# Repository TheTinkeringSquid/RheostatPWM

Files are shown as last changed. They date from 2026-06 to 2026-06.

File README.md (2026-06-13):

# Dodge B2500 Instrument Cluster LED PWM Dimmer

Small RP2040-based PWM dimmer board for a 1996 Dodge B2500 instrument cluster
LED conversion. It reads the factory headlight rheostat as an analog input and
drives the cluster illumination feed with a protected high-side 12 V PWM output.

> **Cluster illumination only.** This board is not for exterior lighting, brake
> lights, turn signals, airbags, engine controls, or any safety-critical
> circuit.

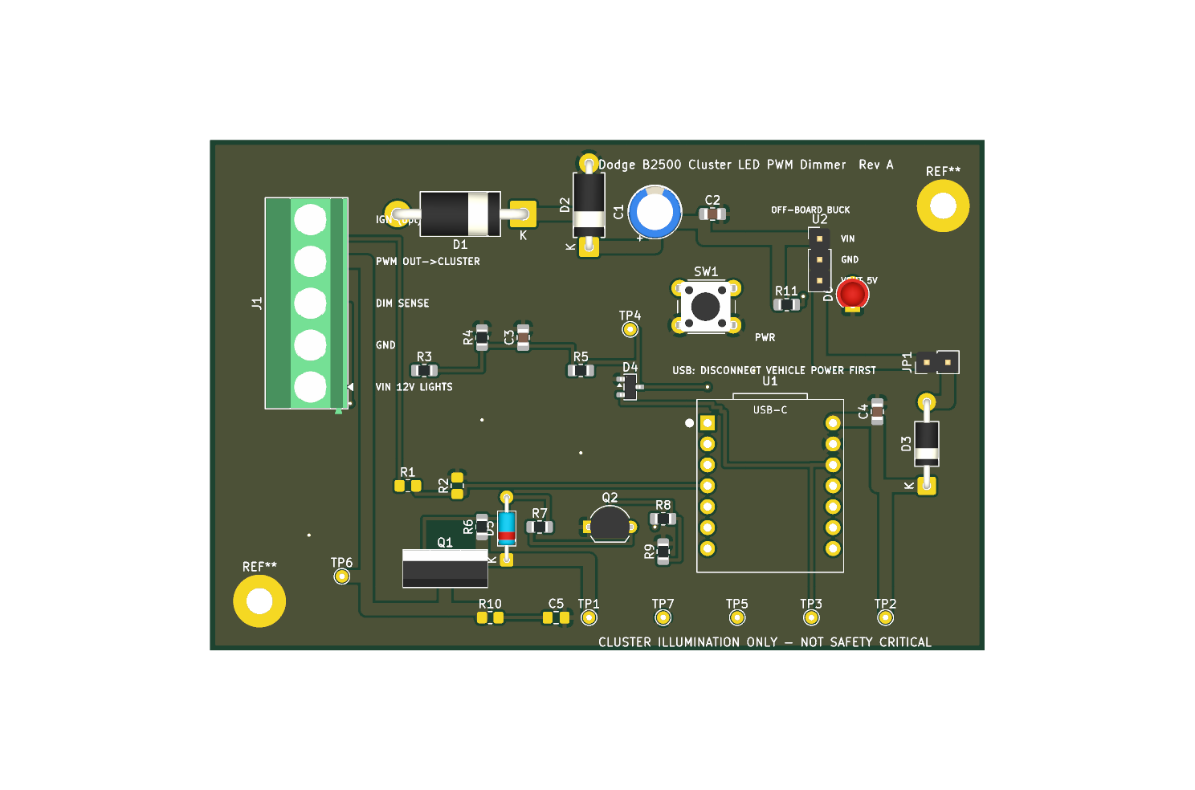
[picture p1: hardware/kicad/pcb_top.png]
PCB top view


---

## How it works

```
factory full 12 V illumination/headlamp-switched feed  -> J1 VIN_RAW
factory dimmer/rheostat analog output                  -> J1 DIM_IN  (sense only)
board high-side 12 V PWM output                        -> J1 PWM_OUT -> cluster LED +
cluster/chassis ground                                 -> J1 GND
```

The factory rheostat no longer powers the cluster lamps. It is read as a
low-current analog control signal through a high-impedance divider into the
XIAO RP2040 ADC. Firmware maps that voltage through a gamma curve to a high-side
PWM output (P-channel MOSFET Q1 driven by N-MOSFET Q2), so the lamp grounds stay
factory.

### Connector (J1)

| Pin | Net | Description |
|----:|---|---|
| 1 | `VIN_RAW`  | Fused full 12 V illumination/headlight-switched feed |
| 2 | `GND` | Chassis/cluster ground |
| 3 | `DIM_IN` | Factory rheostat output, sense only |
| 4 | `PWM_OUT`  | PWM +12 V output to cluster LED illumination feed |
| 5 | `IGN_SENSE`| Optional lights-on signal (future firmware; DNP parts) |

### Install concept

1. Identify the factory cluster illumination/dimmer feed with a multimeter and
   wiring diagram.
2. Cut or depin the cluster illumination feed so the rheostat no longer powers
   the LED bulbs directly.
3. Connect the **vehicle/rheostat side** of that wire to `DIM_IN`.
4. Connect the **cluster/lamp side** of that wire to `PWM_OUT`.
5. Power the board from a fused full-bright illumination feed that is hot when
   park/headlights are on — **not** from the dimmed rheostat output.
6. Ground the board to the cluster/chassis ground.

> Do **not** power the microcontroller from `DIM_IN`; it may brown out when the
> rheostat is turned down.
>
> If the factory dimmer turns out to be low-side, already-PWM, or multiplexed
> rather than a simple variable positive voltage, **stop** and revise the input
> circuit instead of forcing this design.

---

## Repository layout

```
.
├── README.md
├── firmware/                     PlatformIO project (Seeed XIAO RP2040)
│   ├── platformio.ini
│   └── src/main.cpp
└── hardware/
    ├── kicad/
    │   ├── b2500_cluster_pwm_dimmer.kicad_pro / .kicad_sch / .kicad_pcb
    │   ├── b2500_cluster_pwm_dimmer_schematic.pdf
    │   ├── pcb_top.png
    │   └── symbols_and_footprints/b2500.pretty/   (XIAO + Pololu module footprints)
    ├── scripts/                  generators (re-create the design deterministically)
    │   ├── netlist.py            single source of truth for the netlist
    │   ├── gen_sch.py            -> kicad_sch
    │   ├── gen_pcb.py            -> kicad_pcb
    │   ├── gen_bom.py            -> BOM CSV
    │   └── export_fab.py         -> gerbers + drill + BOM (run after routing)
    ├── gerbers/                  fabrication output (generated after routing)
    ├── fabrication_notes.md
    └── b2500_cluster_pwm_dimmer_bom.csv
```

The KiCad schematic, board, and BOM are generated by the scripts in
`hardware/scripts/`. They share `netlist.py` so the schematic and board can
never drift apart. Regenerate with:

```powershell
python hardware/scripts/gen_sch.py                       # schematic
& "C:/Program Files/KiCad/10.0/bin/python.exe" hardware/scripts/gen_pcb.py   # board (needs KiCad's Python)
python hardware/scripts/gen_bom.py                       # BOM CSV
```

---

## Firmware

Built with PlatformIO for the Seeed Studio XIAO RP2040 (Arduino / Earle
Philhower RP2040 core).

```bash
cd firmware
pio run            # build
pio run -t upload  # flash (board in UF2 bootloader, or via USB)
pio device monitor # 115200 baud serial debug
```

Key calibration constants live at the top of `firmware/src/main.cpp`
(`ADC_OFF_THRESHOLD`, `ADC_MIN_INPUT`, `ADC_MAX_INPUT`, `DUTY_MIN`, `GAMMA`,
`PWM_FREQ_HZ`, plus `REVERSE_DIMMER_DIRECTION`). Tune them on the bench against
the real dimmer using the serial output. PWM defaults to 976 Hz (in the
500 Hz–2 kHz target band).

---

## PCB

The board is **fully routed and DRC-clean** (0 violations, 0 unconnected) —
2 layers, 94 × 62 mm, ground pour on both. `hardware/scripts/gen_pcb.py`
places every part, pours ground, and routes all nets with a built-in
collision-aware router (Manhattan + maze fallback): high-current nets
(`VIN_RAW`, `PWM_OUT`, `VIN_PROT`) at 1.5 mm, signals at 0.4 mm. The gerbers and
drill files in `hardware/gerbers/` are ready to send to a fabricator.

You don't need to touch KiCad to get the board made. If you *want* to inspect or
tweak it:

1. Open `hardware/kicad/b2500_cluster_pwm_dimmer.kicad_pro` in KiCad 10.
2. Make changes, run DRC, then regenerate fabrication output:

   ```powershell
   python hardware/scripts/export_fab.py
   ```

   This runs DRC, writes gerbers + Excellon drill to `hardware/gerbers/`, and
   regenerates the BOM. (Re-running `gen_pcb.py` regenerates the whole board
   from scratch and will discard manual KiCad edits.)

### Ordering the board

Zip the contents of `hardware/gerbers/` and upload to any PCB fab (JLCPCB,
PCBWay, OSH Park, Aisler, etc.): 2-layer, 1.6 mm, 1 oz copper (2 oz is a nice
upgrade for the power path), HASL or ENIG. See
[hardware/fabrication_notes.md](hardware/fabrication_notes.md) for the full
spec, assembly notes, and the bench/in-vehicle test procedures.

---

## Deviations from the original brief

- **Board size** is ~94 × 62 mm, not the 50 × 35 mm target. The through-hole
  part set (5-pos 5.08 mm terminal block, TO-220, two modules, radial cap, seven
  test points, button) does not fit smaller while staying hand-solderable. A
  compact SMD-MOSFET / smaller-connector variant is a sensible future revision.
- **Q1 gate pull-up R6 is 10 k (brief said 47 k)** and a **DNP R10/C5 RC snubber
  footprint** sits across `PWM_OUT` — both for a cleaner, better-defined
  high-side switching edge with less ringing/EMI. Fit the snubber only if the
  bench scope shows ringing.
- **The buck regulator (U2) mounts off-board**, wired to a labeled 3-pin
  header (`VIN`/`GND`/`VOUT`). A footprint audit against the Pololu module
  showed its on-board land is easy to get wrong (6 pins incl. an offset PG, two
  GNDs); a wired connection is order-proof and far safer to assemble by hand.
- **Two M3 mounting holes** (per the BOM, M1–M2), placed diagonally — the
  terminal block fills the left edge, so a top-left hole was not possible.
- The board is routed by a **purpose-built script router**, not by hand in
  KiCad. It is DRC-clean and electrically complete, but the trace paths are
  Manhattan/maze-style rather than artistically dressed; feel free to prettify
  in the GUI if you re-spin.
- The XIAO USB-C port is not on a board edge; for in-place reflashing, prefer
  the UF2 bootloader or relocate U1 to an edge in a future revision.

## Safety

- Always fuse `VIN_RAW` (inline blade fuse in the harness — F1 is not on the
  board). Size it to the measured LED cluster current.
- Do not route the cluster output back through the factory rheostat.
- Do not connect USB while the board is vehicle-powered unless JP1 is open / the
  D3 isolation diode is fitted, to avoid 5 V backfeed.
- This is not OEM-grade load-dump protection. The TVS + wide-input regulator
  reduce risk but do not eliminate it.
- Carry a bypass jumper during early testing so the cluster lamps can be
  restored if the board fails.

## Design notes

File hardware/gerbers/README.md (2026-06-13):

# Gerbers

Fabrication output for the B2500 cluster PWM dimmer — RS-274X gerbers plus
Excellon drill files (`-PTH.drl`, `-NPTH.drl`). The board is fully routed and
DRC-clean, so these are **ready to manufacture**.

To order: zip the contents of this directory and upload to any PCB fab
(JLCPCB, PCBWay, OSH Park, Aisler, …). Settings: 2-layer, 1.6 mm, 1 oz copper
(2 oz optional for the power path), HASL or ENIG.

These files are generated, not hand-edited. Regenerate after any board change
with:

```powershell
python ../scripts/export_fab.py
```

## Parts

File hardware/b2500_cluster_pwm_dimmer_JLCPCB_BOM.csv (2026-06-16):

Comment | Designator | Footprint | LCSC Part#
100nF 50V | C2,C3 | 0805
10uF | C4 | 0805
100k 1% | R3,R9 | 0805
22k 1% | R4 | 0805
1k | R5 | 0805
10k | R6 | 0805
100R | R7,R8 | 0805
3.3k | R11 | 0805
BAT54S | D4 | SOT-23

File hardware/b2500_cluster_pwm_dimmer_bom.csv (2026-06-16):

Refs | Qty | Value | Footprint | Fit | Notes
C1 | 1 | 47uF 50V | Capacitor_THT:CP_Radial_D6.3mm_P2.50mm | FIT
C2 | 1 | 100nF 50V | Capacitor_SMD:C_0805_2012Metric_Pad1.18x1.45mm_HandSolder | FIT
C3 | 1 | 100nF | Capacitor_SMD:C_0805_2012Metric_Pad1.18x1.45mm_HandSolder | FIT
C4 | 1 | 10uF | Capacitor_SMD:C_0805_2012Metric_Pad1.18x1.45mm_HandSolder | FIT
C5 | 1 | 10nF 100V (DNP) | Capacitor_SMD:C_0805_2012Metric_Pad1.18x1.45mm_HandSolder | DNP | DNP RC snubber across PWM_OUT (fit only if edge ringing)
D1 | 1 | 1N5822 | Diode_THT:D_DO-201AD_P15.24mm_Horizontal | FIT | reverse-polarity series Schottky, >=3A >=40V
D2 | 1 | P6KE24CA | Diode_THT:D_DO-15_P10.16mm_Horizontal | FIT | TVS across protected VIN-GND
D3 | 1 | 1N5819 | Diode_THT:D_DO-41_SOD81_P10.16mm_Horizontal | FIT | optional 5V isolation diode (USB backfeed)
D4 | 1 | BAT54S | Package_TO_SOT_SMD:SOT-23 | FIT | ADC clamp to 3V3/GND
D5 | 1 | 1N5242B 12V | Diode_THT:D_DO-35_SOD27_P7.62mm_Horizontal | FIT | 12V zener, Q1 gate-source protection
D6 | 1 | Green LED (PWR) | LED_THT:LED_D3.0mm | FIT | green power-on LED (lit whenever 12V is present); 3mm through-hole
F1 | 1 | 2A mini blade, INLINE IN HARNESS |  | OFF-BOARD | OFF-BOARD: inline blade fuse in the vehicle harness; size to LED current
J1 | 1 | Phoenix MKDS-1,5-5-5.08 | TerminalBlock_Phoenix:TerminalBlock_Phoenix_MKDS-1,5-5-5.08_1x05_P5.08mm_Horizontal | FIT | 5-pos 5.08mm pluggable terminal (or locking automotive conn)
JP1 | 1 | 5V_LINK | Connector_PinHeader_2.54mm:PinHeader_1x02_P2.54mm_Vertical | FIT | open to isolate vehicle 5V during USB programming
Q1 | 1 | FQP27P06 | Package_TO_SOT_THT:TO-220-3_Vertical | FIT | >=40V Vds, >=2A, low Rds(on); TO-220
Q2 | 1 | 2N7000 | Package_TO_SOT_THT:TO-92_Inline_Wide | FIT | small logic-level N-MOSFET / 2N7000
R1 | 1 | 100k (DNP) | Resistor_SMD:R_0805_2012Metric_Pad1.20x1.40mm_HandSolder | DNP | DNP IGN-sense divider (future firmware)
R10 | 1 | 100R (DNP) | Resistor_SMD:R_0805_2012Metric_Pad1.20x1.40mm_HandSolder | DNP | DNP RC snubber across PWM_OUT (fit only if edge ringing)
R11 | 1 | 3.3k | Resistor_SMD:R_0805_2012Metric_Pad1.20x1.40mm_HandSolder | FIT | series resistor for D6 power LED (~3 mA at 12 V)
R2 | 1 | 22k (DNP) | Resistor_SMD:R_0805_2012Metric_Pad1.20x1.40mm_HandSolder | DNP | DNP IGN-sense divider (future firmware)
R3 | 1 | 100k 1% | Resistor_SMD:R_0805_2012Metric_Pad1.20x1.40mm_HandSolder | FIT
R4 | 1 | 22k 1% | Resistor_SMD:R_0805_2012Metric_Pad1.20x1.40mm_HandSolder | FIT
R5 | 1 | 1k | Resistor_SMD:R_0805_2012Metric_Pad1.20x1.40mm_HandSolder | FIT
R6 | 1 | 10k | Resistor_SMD:R_0805_2012Metric_Pad1.20x1.40mm_HandSolder | FIT
R7,R8 | 2 | 100R | Resistor_SMD:R_0805_2012Metric_Pad1.20x1.40mm_HandSolder | FIT
R9 | 1 | 100k | Resistor_SMD:R_0805_2012Metric_Pad1.20x1.40mm_HandSolder | FIT
SW1 | 1 | CAL | Button_Switch_THT:SW_PUSH_6mm | FIT
TP1 | 1 | TP_VIN | TestPoint:TestPoint_THTPad_D1.5mm_Drill0.7mm | FIT
TP2 | 1 | TP_5V | TestPoint:TestPoint_THTPad_D1.5mm_Drill0.7mm | FIT
TP3 | 1 | TP_3V3 | TestPoint:TestPoint_THTPad_D1.5mm_Drill0.7mm | FIT
TP4 | 1 | TP_DIM_ADC | TestPoint:TestPoint_THTPad_D1.5mm_Drill0.7mm | FIT
TP5 | 1 | TP_PWM_GATE | TestPoint:TestPoint_THTPad_D1.5mm_Drill0.7mm | FIT
TP6 | 1 | TP_PWM_OUT | TestPoint:TestPoint_THTPad_D1.5mm_Drill0.7mm | FIT
TP7 | 1 | TP_GND | TestPoint:TestPoint_THTPad_D1.5mm_Drill0.7mm | FIT
U1 | 1 | XIAO RP2040 | b2500:XIAO_RP2040_THT | FIT | Seeed XIAO RP2040 module on 2x7 socket headers
U2 | 1 | Pololu D36V28F5 (off-board, wired) | Connector_PinHeader_2.54mm:PinHeader_1x03_P2.54mm_Vertical | FIT | Pololu D36V28F5 buck module, mounted OFF-BOARD; wire its VIN/GND/VOUT to the 3-pin header (match label to label)

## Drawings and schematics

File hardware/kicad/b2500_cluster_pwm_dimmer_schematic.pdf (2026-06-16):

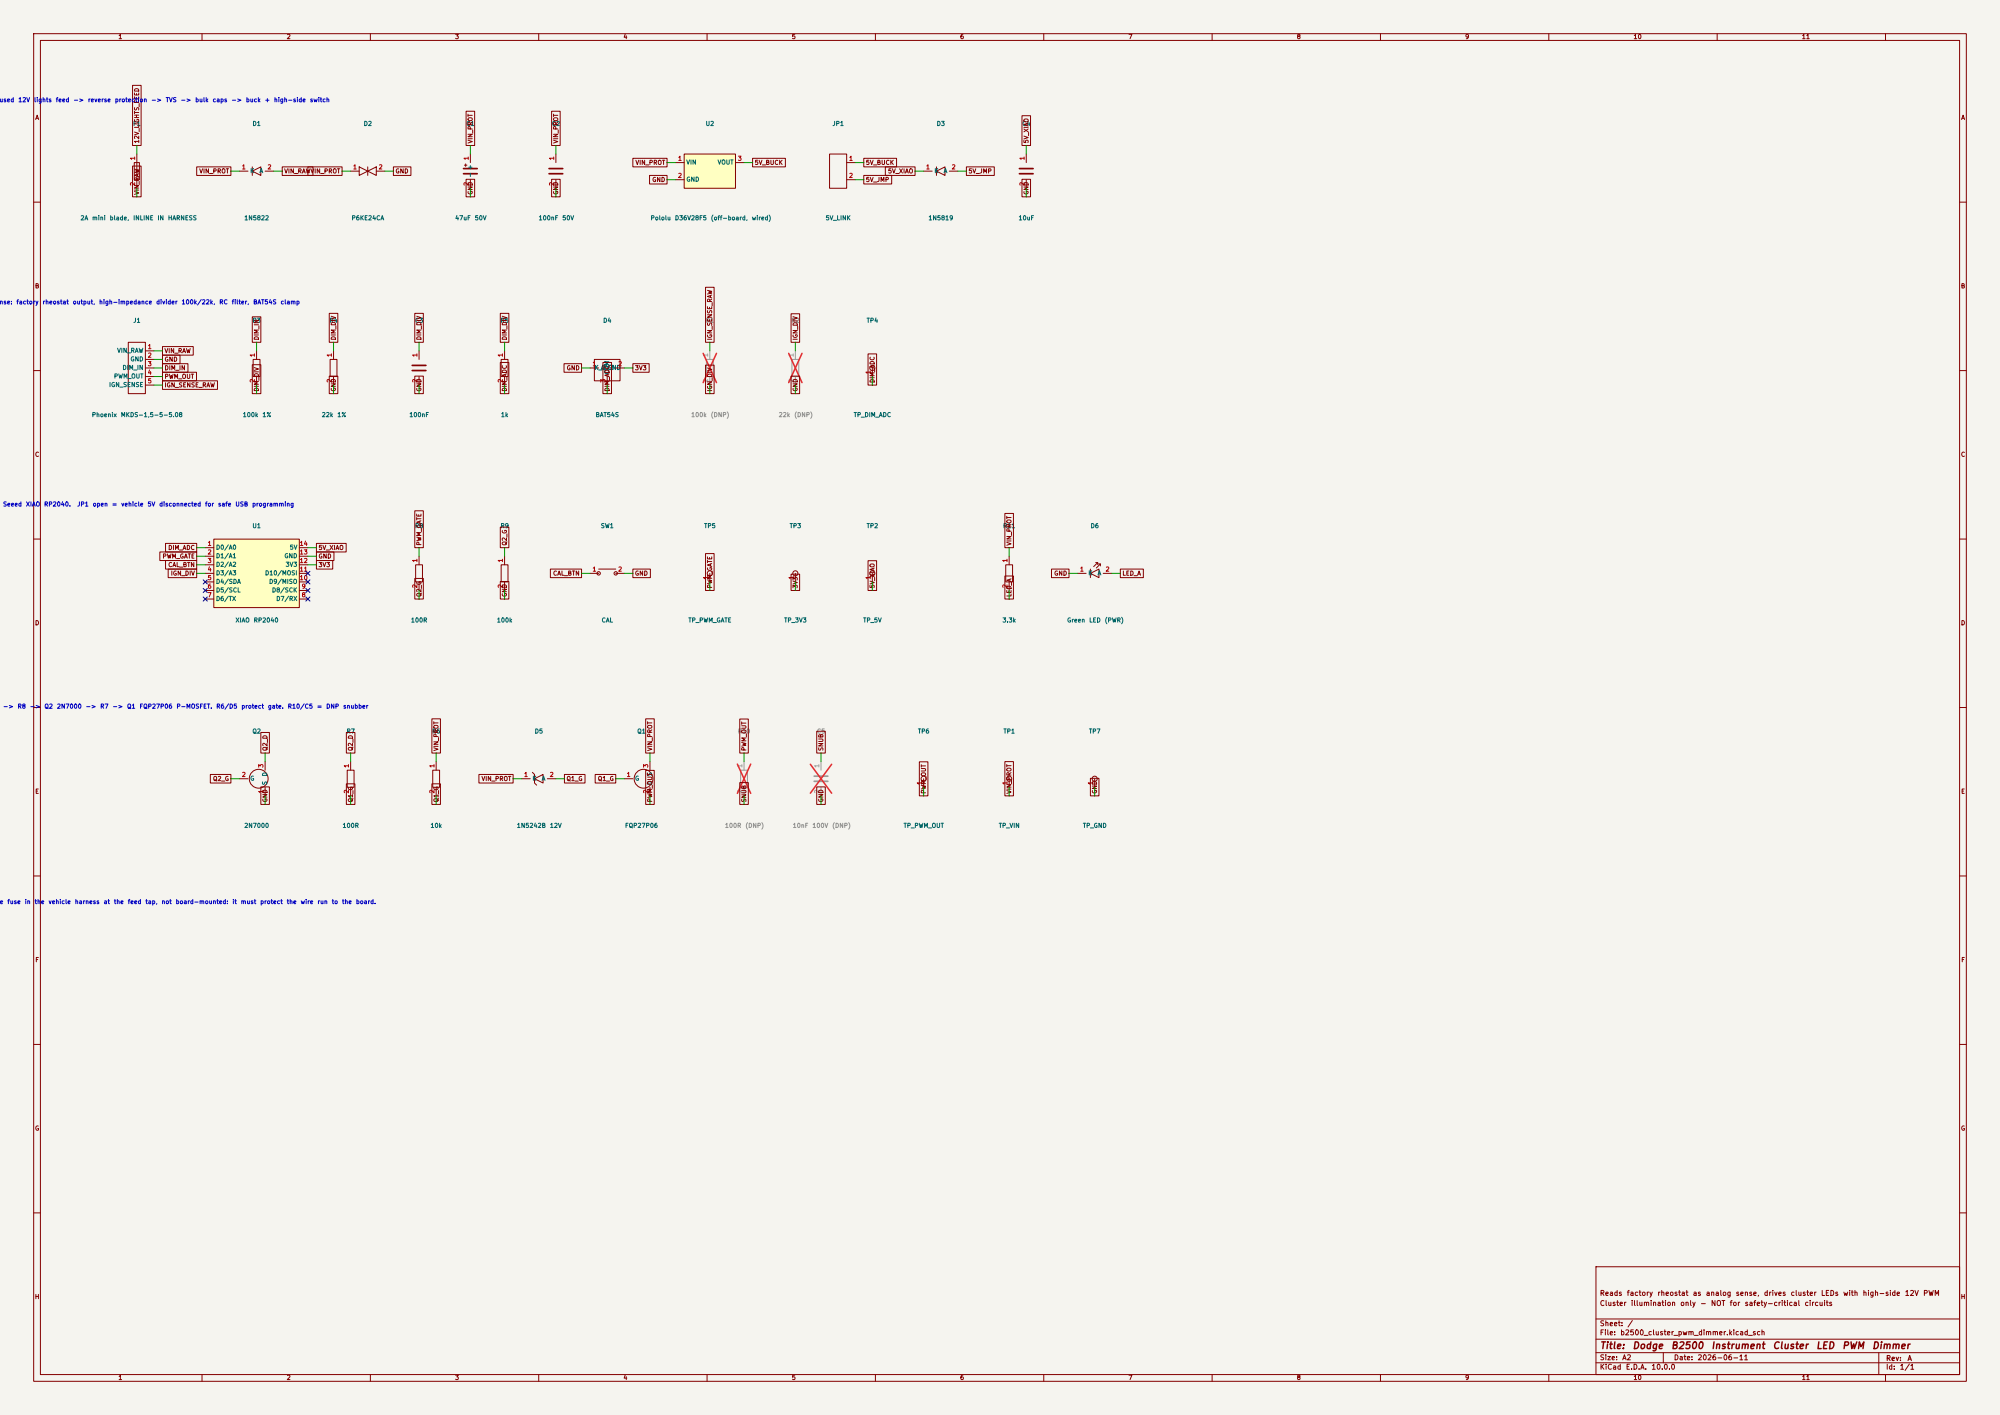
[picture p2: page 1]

Power input: fused 12V lights feed -> reverse protection -> TVS -> bulk caps -> buck + high-side switch

2A mini blade, INLINE IN HARNESS

DIM sense: factory rheostat output, high-impedance divider 100k/22k, RC filter, BAT54S clamp

MCU: Seeed XIAO RP2040. JP1 open = vehicle 5V disconnected for safe USB programming

3V3 High-side PWM: D1(MCU) -> R8 -> Q2 2N7000 -> R7 -> Q1 FQP27P06 P-MOSFET. R6/D5 protect gate. R10/C5 = DNP snubber F1 is an INLINE mini-blade fuse in the vehicle harness at the feed tap, not board-mounted: it must protect the wire run to the board.

Cluster illumination only - NOT for safety-critical circuits Reads factory rheostat as analog sense, drives cluster LEDs with high-side 12V PWM

Sheet: /
File: b2500_cluster_pwm_dimmer.kicad_sch
Title: Dodge B2500 Instrument Cluster LED PWM Dimmer

Size: A2 | Rev: A

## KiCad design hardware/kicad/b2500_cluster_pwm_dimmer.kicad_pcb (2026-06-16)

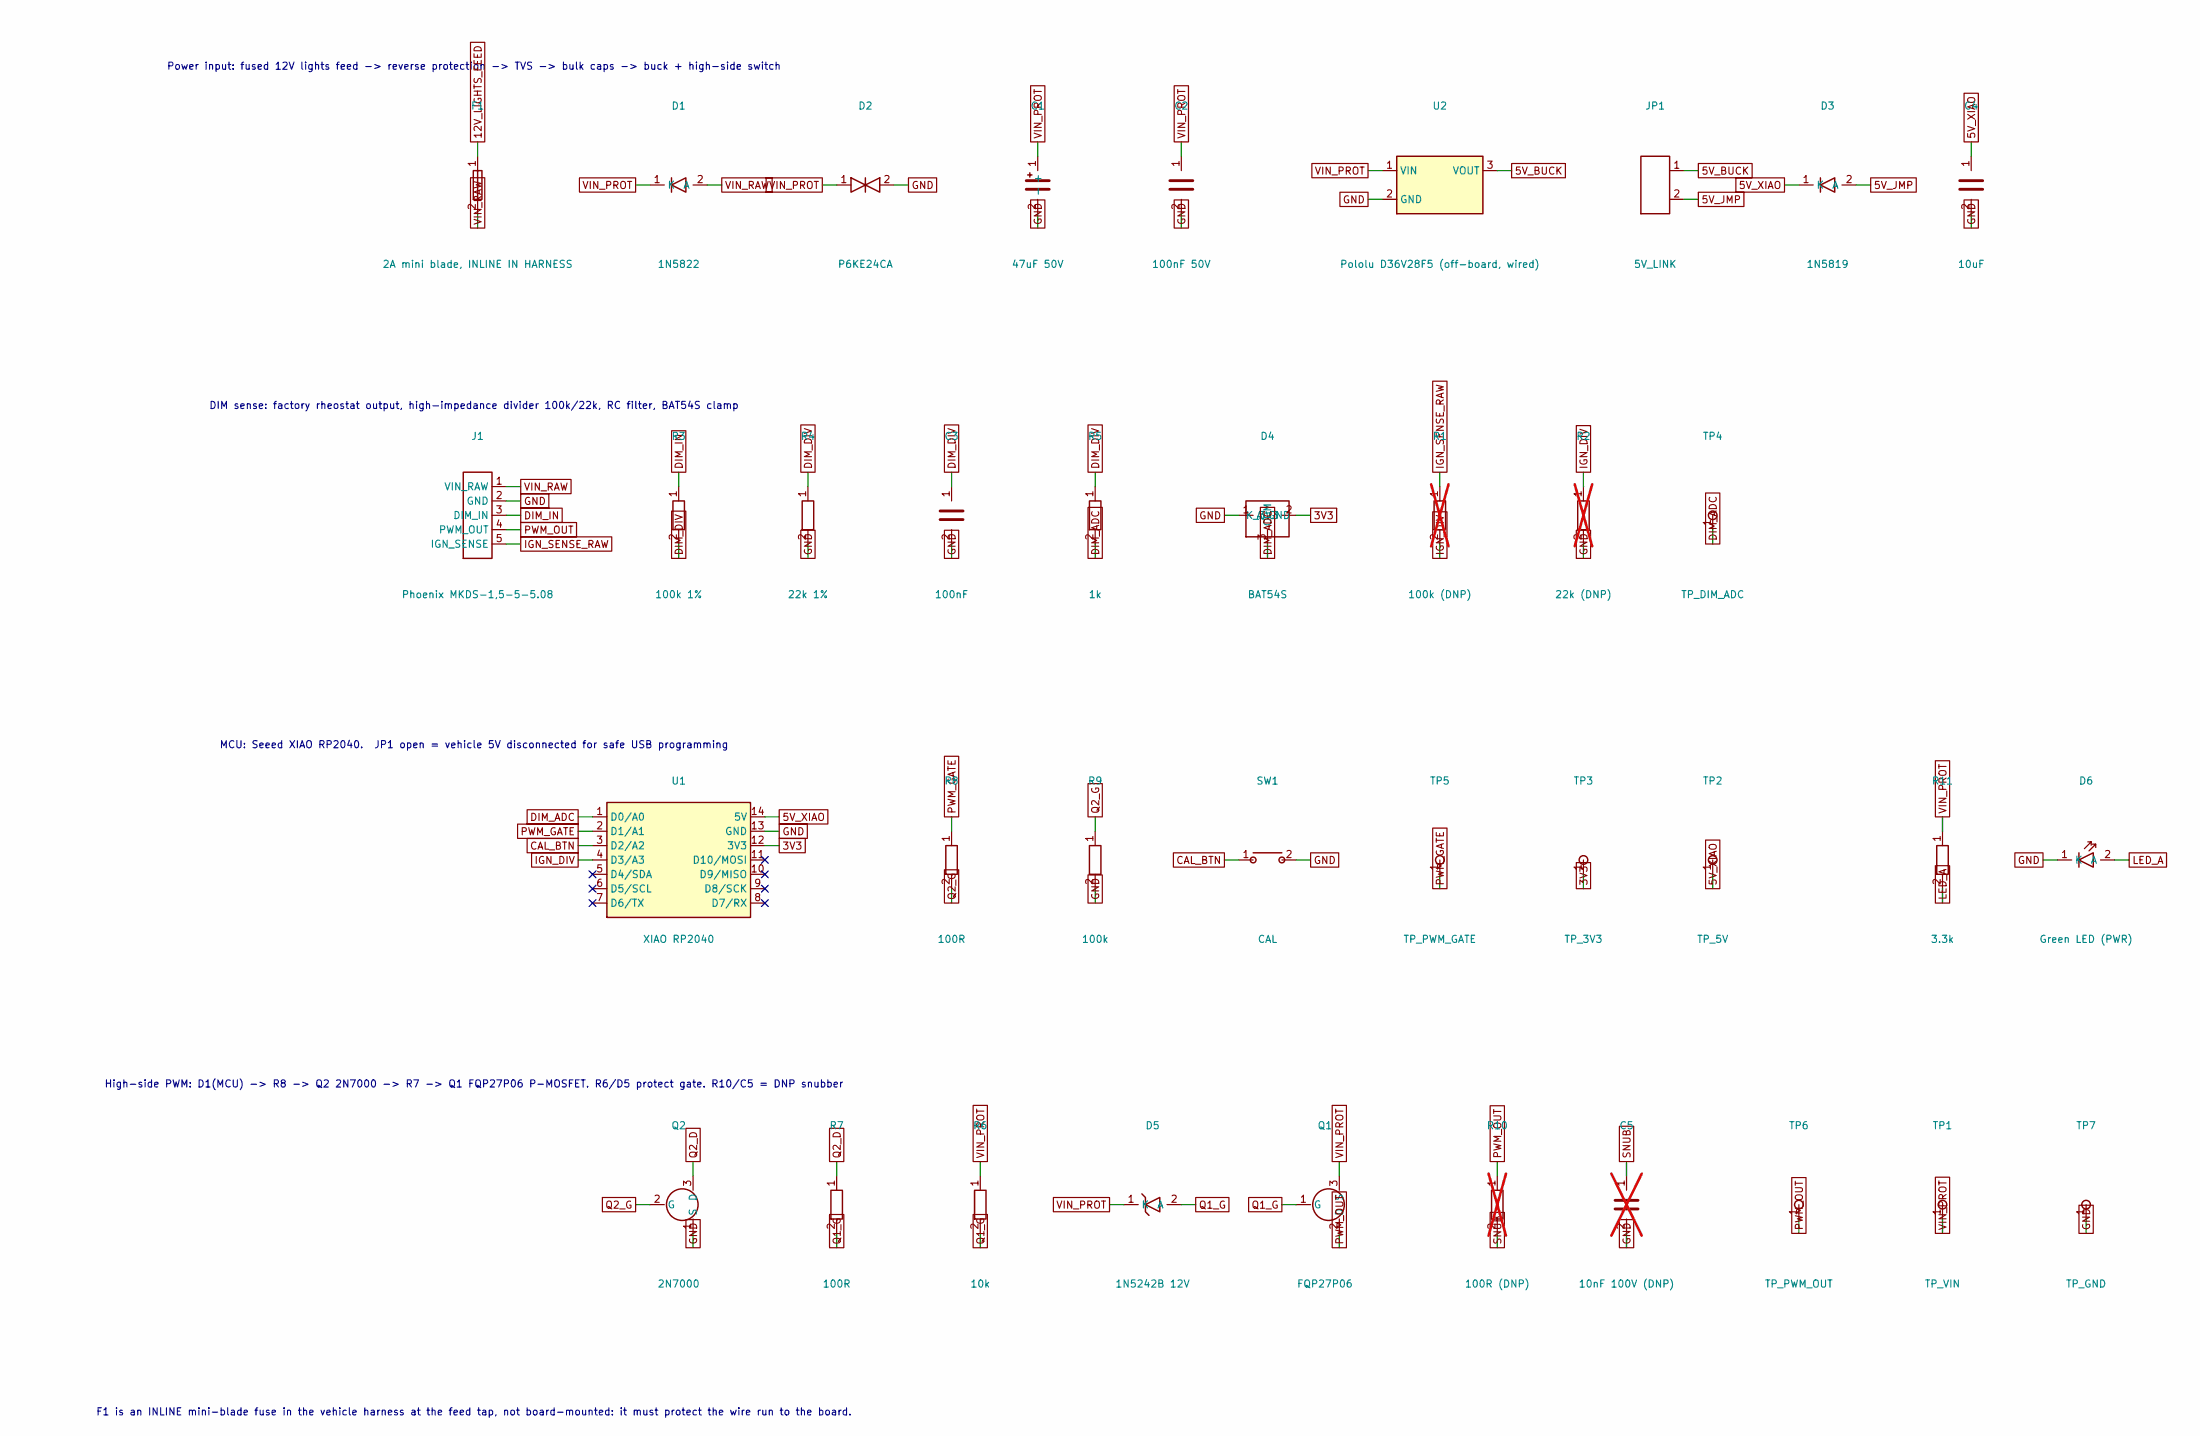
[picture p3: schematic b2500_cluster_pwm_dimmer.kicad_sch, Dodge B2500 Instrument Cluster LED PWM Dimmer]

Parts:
C1: 47uF 50V; CP_Radial_D6.3mm_P2.50mm
C2: 100nF 50V; C_0805_2012Metric_Pad1.18x1.45mm_HandSolder
C3: 100nF; C_0805_2012Metric_Pad1.18x1.45mm_HandSolder
C4: 10uF; C_0805_2012Metric_Pad1.18x1.45mm_HandSolder
C5: 10nF 100V (DNP); C_0805_2012Metric_Pad1.18x1.45mm_HandSolder; not fitted
D1: 1N5822; D_DO-201AD_P15.24mm_Horizontal
D2: P6KE24CA; D_DO-15_P10.16mm_Horizontal
D3: 1N5819; D_DO-41_SOD81_P10.16mm_Horizontal
D4: BAT54S; SOT-23
D5: 1N5242B 12V; D_DO-35_SOD27_P7.62mm_Horizontal
D6: Green LED (PWR); LED_D3.0mm
F1: 2A mini blade, INLINE IN HARNESS
J1: Phoenix MKDS-1,5-5-5.08; TerminalBlock_Phoenix_MKDS-1,5-5-5.08_1x05_P5.08mm_Horizont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
JP1: 5V_LINK; PinHeader_1x02_P2.54mm_Vertical
Q1: FQP27P06; TO-220-3_Vertical
Q2: 2N7000; TO-92_Inline_Wide
R1: 100k (DNP); R_0805_2012Metric_Pad1.20x1.40mm_HandSolder; not fitted
R2: 22k (DNP); R_0805_2012Metric_Pad1.20x1.40mm_HandSolder; not fitted
R3: 100k 1%; R_0805_2012Metric_Pad1.20x1.40mm_HandSolder
R4: 22k 1%; R_0805_2012Metric_Pad1.20x1.40mm_HandSolder
R5: 1k; R_0805_2012Metric_Pad1.20x1.40mm_HandSolder
R6: 10k; R_0805_2012Metric_Pad1.20x1.40mm_HandSolder
R7, R8: 100R; R_0805_2012Metric_Pad1.20x1.40mm_HandSolder
R9: 100k; R_0805_2012Metric_Pad1.20x1.40mm_HandSolder
R10: 100R (DNP); R_0805_2012Metric_Pad1.20x1.40mm_HandSolder; not fitted
R11: 3.3k; R_0805_2012Metric_Pad1.20x1.40mm_HandSolder
SW1: CAL; SW_PUSH_6mm
TP1: TP_VIN; TestPoint_THTPad_D1.5mm_Drill0.7mm
TP2: TP_5V; TestPoint_THTPad_D1.5mm_Drill0.7mm
TP3: TP_3V3; TestPoint_THTPad_D1.5mm_Drill0.7mm
TP4: TP_DIM_ADC; TestPoint_THTPad_D1.5mm_Drill0.7mm
TP5: TP_PWM_GATE; TestPoint_THTPad_D1.5mm_Drill0.7mm
TP6: TP_PWM_OUT; TestPoint_THTPad_D1.5mm_Drill0.7mm
TP7: TP_GND; TestPoint_THTPad_D1.5mm_Drill0.7mm
U1: XIAO RP2040; XIAO_RP2040_THT
U2: Pololu D36V28F5 (off-board, wired); PinHeader_1x03_P2.54mm_Vertical

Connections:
3V3: D4.2 (K_3V3), TP3.1, U1.12 (3V3)
5V_BUCK: JP1.1, U2.3 (VOUT)
5V_JMP: D3.2 (A), JP1.2
5V_XIAO: C4.1, D3.1 (K), TP2.1, U1.14 (5V)
CAL_BTN: SW1.1, U1.3 (D2/A2)
DIM_ADC: D4.3 (COM), R5.2, TP4.1, U1.1 (D0/A0)
DIM_DIV: C3.1, R3.2, R4.1, R5.1
DIM_IN: J1.3 (DIM_IN), R3.1
GND: C1.2 (-), C2.2, C3.2, C4.2, C5.2, D2.2, D4.1 (A_GND), D6.1 (K), J1.2 (GND), Q2.1 (S), R2.2, R4.2, R9.2, SW1.2, TP7.1, U1.13 (GND), U2.2 (GND)
IGN_DIV: R1.2, R2.1, U1.4 (D3/A3)
IGN_SENSE_RAW: J1.5 (IGN_SENSE), R1.1
LED_A: D6.2 (A), R11.2
PWM_GATE: R8.1, TP5.1, U1.2 (D1/A1)
PWM_OUT: J1.4 (PWM_OUT), Q1.2 (D), R10.1, TP6.1
Q1_G: D5.2 (A), Q1.1 (G), R6.2, R7.2
Q2_D: Q2.3 (D), R7.1
Q2_G: Q2.2 (G), R8.2, R9.1
SNUB: C5.1, R10.2
VIN_PROT: C1.1 (+), C2.1, D1.1 (K), D2.1, D5.1 (K), Q1.3 (S), R6.1, R11.1, TP1.1, U2.1 (VIN)
VIN_RAW: D1.2 (A), F1.2, J1.1 (VIN_RAW)

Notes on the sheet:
Power input: fused 12V lights feed -> reverse protection -> TVS -> bulk caps -> buck + high-side switch
DIM sense: factory rheostat output, high-impedance divider 100k/22k, RC filter, BAT54S clamp
MCU: Seeed XIAO RP2040. JP1 open = vehicle 5V disconnected for safe USB programming
High-side PWM: D1(MCU) -> R8 -> Q2 2N7000 -> R7 -> Q1 FQP27P06 P-MOSFET. R6/D5 protect gate. R10/C5 = DNP snubber
F1 is an INLINE mini-blade fuse in the vehicle harness at the feed tap, not board-mounted: it must protect the wire run to the board.

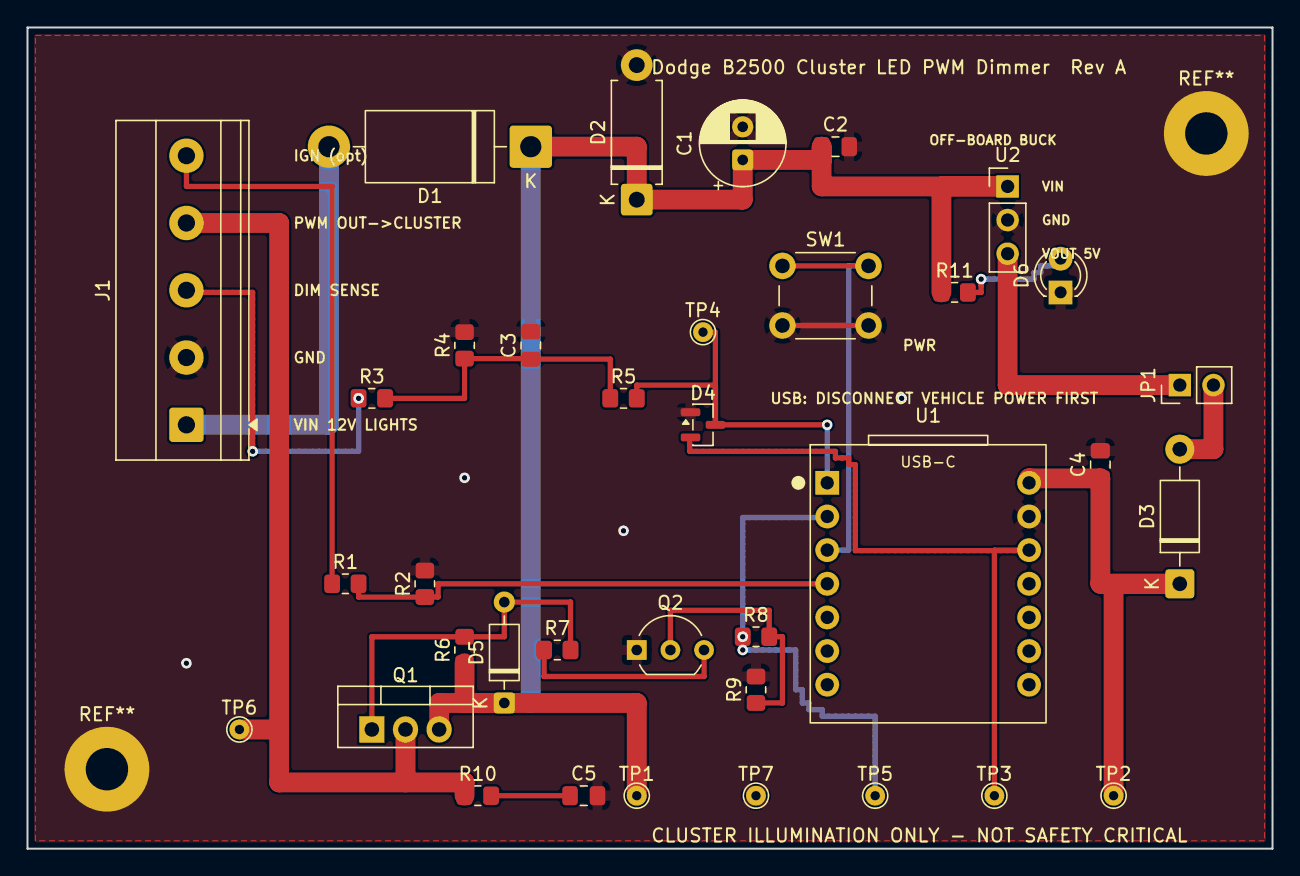
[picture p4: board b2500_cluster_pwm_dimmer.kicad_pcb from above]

Board: 2 copper layers, 94.0 x 62.0 mm, 36 parts (0 on the bottom side), 20 nets.

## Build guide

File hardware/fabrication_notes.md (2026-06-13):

# Fabrication & Assembly Notes

> **This board is for instrument-cluster illumination only.** It is not for
> exterior lighting, brake lights, turn signals, airbags, engine controls, or
> any safety-critical circuit. Do not use it outside its intended purpose.

## Board specification

| Item | Value |
|---|---|
| Layers | 2 (signal/F.Cu + signal/B.Cu), ground pour on both |
| Size | ~94 × 62 mm |
| Copper weight | 1 oz (35 µm) minimum; 2 oz preferred for the power path |
| Min track / clr | 0.25 mm / 0.20 mm (power nets routed 1.5 mm) |
| Min hole | 0.3 mm; vias 0.8 mm / 0.4 mm |
| Finish | HASL or ENIG, lead-free |
| Mounting | 2 × M3 (GND-connected pads) |

## Routing status

The committed `b2500_cluster_pwm_dimmer.kicad_pcb` is **fully routed and
DRC-clean** (0 violations, 0 unconnected items). The gerbers and Excellon drill
files in `hardware/gerbers/` are ready to send to a fabricator as-is.

High-current nets (`VIN_RAW`, `PWM_OUT`, `VIN_PROT`) are routed at 1.5 mm,
signals at 0.4 mm. The `DIM_IN`/ADC divider sits away from the Q1 switching node
as the brief requires. To regenerate everything after any change:

```powershell
python hardware/scripts/export_fab.py
```

This re-runs DRC and rewrites the gerbers, drill, and BOM. (Note: re-running
`gen_pcb.py` rebuilds the board from scratch and discards manual KiCad edits.)

## Assembly notes

- **F1 is OFF-BOARD.** Use an inline blade fuse in the vehicle harness at the
  feed tap, sized to the measured LED cluster current (1–2 A typical). It must
  protect the wire run to the board.
- **U1 (XIAO RP2040)** mounts on two 1×7 socket headers so it is removable; the
  USB-C connector is used for programming.
- **U2 (Pololu D36V28F5)** mounts **off-board** and is wired to the 3-pin
  header labeled `OFF-BOARD BUCK` (`VIN` / `GND` / `VOUT 5V`). Run three short
  wires from the module's matching pins to this header — **match label to
  label**. This is orientation-proof, so the module's exact pin order does not
  matter. The module's EN pin can be left unconnected (it is enabled by
  default); PG is unused. Mount the module with double-sided tape or a standoff.
- **Q1 (FQP27P06, TO-220)** is the high-side P-MOSFET. Leave clearance around the
  tab; add a small heatsink only if bench testing shows it running warm (it
  should stay cool at <1 A LED load).
- **Do-not-populate (DNP):**
  - `R10` + `C5` — RC snubber across `PWM_OUT`. Fit only if a scope shows
    switching-edge ringing.
  - `R1` + `R2` — `IGN_SENSE` divider reserved for future firmware.
- **JP1** links the buck 5 V to the XIAO 5 V. Leave it **open** when programming
  over USB with vehicle power applied, to prevent 5 V backfeed (D3 also helps).
- Test points: `TP_VIN`, `TP_5V`, `TP_3V3`, `TP_DIM_ADC`, `TP_PWM_GATE`,
  `TP_PWM_OUT`, `TP_GND`.

---

## Bench test procedure (before installing in the van)

1. Build the PCB; do **not** connect it to the van.
2. Inspect for shorts.
3. Power from a current-limited bench supply at 12 V.
4. Confirm the 5 V rail (`TP_5V`) and 3.3 V rail (`TP_3V3`).
5. Drive `DIM_IN` with a potentiometer or adjustable supply (0–14.4 V).
6. Connect a 12 V LED test lamp (or resistor + LED) to `PWM_OUT`.
7. Sweep `DIM_IN` from 0 V to 14.4 V and verify:
   - LEDs off near zero input.
   - Smooth brightness increase.
   - Full brightness near full dimmer input.
   - Q1 does not get hot.
   - No XIAO brownouts.
8. Scope `TP_PWM_OUT` / `TP_PWM_GATE` to confirm PWM frequency (~976 Hz) and a
   clean edge. Fit the R10/C5 snubber if you see ringing.
9. Tune firmware constants `ADC_OFF_THRESHOLD`, `ADC_MIN_INPUT`, `ADC_MAX_INPUT`,
   `DUTY_MIN`, `GAMMA` using the serial monitor (115200 baud):
   - record `filtered=` at lights-off, barely-on, and full-bright;
   - set `ADC_MIN_INPUT` just below barely-on, `ADC_MAX_INPUT` to full-bright,
     `ADC_OFF_THRESHOLD` just above the true-off noise floor.

## In-vehicle test procedure

1. Disconnect the battery before wiring.
2. Verify the factory wire functions with a DMM.
3. Install an inline fuse if the feed is not already appropriately fused.
4. Connect board **ground first**.
5. Connect `VIN_RAW` to a full-bright park/headlight-switched 12 V feed.
6. Connect the rheostat output sense to `DIM_IN`.
7. Connect the cluster LED feed to `PWM_OUT`.
8. Reconnect the battery.
9. Test with parking lights / headlights on. Check:
   - the dimmer knob smoothly adjusts cluster brightness;
   - no flicker while the engine runs;
   - no radio noise;
   - board and MOSFET stay cool;
   - cluster lights turn off when park/headlights are off.

If the dimmer works backward, set `REVERSE_DIMMER_DIRECTION = true` in firmware
(invert in software, not by rewiring power).

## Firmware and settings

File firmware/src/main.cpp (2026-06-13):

#include <Arduino.h>
#include <math.h>

// Dodge B2500 cluster LED PWM dimmer
// Board: Seeed Studio XIAO RP2040
//
// Hardware behavior:
//   DIM_IN -> resistor divider -> A0
//   D1 PWM -> Q2 -> Q1 P-channel high-side MOSFET
//   PWM pin HIGH means cluster LEDs ON, assuming the schematic in this repo.
//
// Install note:
//   Power board from a full 12 V illumination/headlight-switched feed.
//   Do NOT power board from the dimmed rheostat output.

// ---------------- User calibration constants ----------------

// XIAO RP2040 / RP2040 ADC is treated as 12-bit in the Arduino-Pico core.
static constexpr uint16_t ADC_MAX_COUNT = 4095;

// Resistor divider: DIM_IN -> 100k -> ADC node -> 22k -> GND
static constexpr float ADC_REF_VOLTS = 3.30f;
static constexpr float R_TOP_OHMS = 100000.0f;
static constexpr float R_BOTTOM_OHMS = 22000.0f;
static constexpr float DIVIDER_RATIO = R_BOTTOM_OHMS / (R_TOP_OHMS + R_BOTTOM_OHMS);

// PWM configuration.
// Keep this modest for automotive wiring; 976 Hz is a good starting point.
static constexpr uint32_t PWM_FREQ_HZ = 976;
static constexpr uint16_t PWM_RANGE = 4095;

// Pin assignments.
static constexpr pin_size_t PIN_DIM_ADC = A0;
static constexpr pin_size_t PIN_PWM_GATE = D1;
static constexpr pin_size_t PIN_CAL_BUTTON = D2;

// Set true only if your gate driver hardware inverts desired brightness.
static constexpr bool PWM_INVERTED = false;

// Set true if the factory dimmer reads high at dim and low at bright.
static constexpr bool REVERSE_DIMMER_DIRECTION = false;

// ADC thresholds.
// With the 100k/22k divider, 14.4 V at DIM_IN is about 3220 counts.
// Use serial debug to tune these after bench testing with the real dimmer.
static constexpr uint16_t ADC_OFF_THRESHOLD = 10;    // below this, force off
static constexpr uint16_t ADC_MIN_INPUT = 25;        // dimmest usable reading
static constexpr uint16_t ADC_MAX_INPUT = 3220;      // full-bright reading

// Output duty limits.
// Many LED bulbs do not behave nicely at extremely tiny duty cycles.
// Raise MIN_DUTY if the LEDs flicker or drop out at the bottom of the range.
static constexpr uint16_t DUTY_MIN = 20;             // about 0.5%
static constexpr uint16_t DUTY_MAX = PWM_RANGE;

// Perceptual curve.
// 1.0 = linear.
// 1.4-2.2 often feels better for LEDs.
// Lower this if the low end feels too compressed.
static constexpr float GAMMA = 1.60f;

// Smoothing.
// Alpha closer to 1 = more responsive, less smoothing.
// Alpha closer to 0 = smoother, slower.
static constexpr float FILTER_ALPHA = 0.12f;

// Serial print interval.
static constexpr uint32_t DEBUG_INTERVAL_MS = 500;

// ---------------- Internal state ----------------

static float filteredAdc = 0.0f;
static uint32_t lastDebugMs = 0;

static uint16_t readAdcAveraged(pin_size_t pin, uint8_t samples = 16) {
  uint32_t acc = 0;
  for (uint8_t i = 0; i < samples; i++) {
    acc += analogRead(pin);
    delayMicroseconds(250);
  }
  return static_cast<uint16_t>(acc / samples);
}

static float adcToDimVolts(float adcCounts) {
  const float vAdc = (adcCounts / static_cast<float>(ADC_MAX_COUNT)) * ADC_REF_VOLTS;
  return vAdc / DIVIDER_RATIO;
}

static uint16_t desiredDutyFromAdc(float adcCounts) {
  if (adcCounts <= ADC_OFF_THRESHOLD) {
    return 0;
  }

  float x = (adcCounts - static_cast<float>(ADC_MIN_INPUT)) /
            (static_cast<float>(ADC_MAX_INPUT) - static_cast<float>(ADC_MIN_INPUT));

  if (x < 0.0f) x = 0.0f;
  if (x > 1.0f) x = 1.0f;

  if (REVERSE_DIMMER_DIRECTION) {
    x = 1.0f - x;
  }

  // Apply perceptual gamma curve.
  float curved = powf(x, GAMMA);

  uint16_t duty = static_cast<uint16_t>(
      DUTY_MIN + curved * static_cast<float>(DUTY_MAX - DUTY_MIN));

  if (duty > DUTY_MAX) duty = DUTY_MAX;
  return duty;
}

static void writePwmDuty(uint16_t duty) {
  if (duty > PWM_RANGE) duty = PWM_RANGE;

  uint16_t out = duty;
  if (PWM_INVERTED) {
    out = PWM_RANGE - duty;
  }

  analogWrite(PIN_PWM_GATE, out);
}

void setup() {
#if defined(SERIAL_DEBUG)
  Serial.begin(115200);
  delay(500);
  Serial.println();
  Serial.println("Dodge B2500 cluster LED PWM dimmer starting...");
#endif

  pinMode(PIN_DIM_ADC, INPUT);
  pinMode(PIN_PWM_GATE, OUTPUT);
  pinMode(PIN_CAL_BUTTON, INPUT_PULLUP);

  analogReadResolution(12);

#if defined(ARDUINO_ARCH_RP2040)
  // Earle Philhower RP2040 Arduino core supports these.
  analogWriteFreq(PWM_FREQ_HZ);
  analogWriteRange(PWM_RANGE);
#else
  // Other Arduino cores may ignore frequency/range settings.
  analogWriteResolution(12);
#endif

  writePwmDuty(0);

  uint16_t initial = readAdcAveraged(PIN_DIM_ADC, 32);
  filteredAdc = static_cast<float>(initial);
}

void loop() {
  const uint16_t rawAdc = readAdcAveraged(PIN_DIM_ADC, 16);

  // Exponential moving average smoothing.
  filteredAdc = (FILTER_ALPHA * static_cast<float>(rawAdc)) +
                ((1.0f - FILTER_ALPHA) * filteredAdc);

  const uint16_t duty = desiredDutyFromAdc(filteredAdc);
  writePwmDuty(duty);

#if defined(SERIAL_DEBUG)
  const uint32_t now = millis();
  if (now - lastDebugMs >= DEBUG_INTERVAL_MS) {
    lastDebugMs = now;

    const float dimVolts = adcToDimVolts(filteredAdc);
    const float dutyPct = (static_cast<float>(duty) / static_cast<float>(PWM_RANGE)) * 100.0f;

    Serial.print("raw=");
    Serial.print(rawAdc);
    Serial.print(" filtered=");
    Serial.print(filteredAdc, 1);
    Serial.print(" dimV=");
    Serial.print(dimVolts, 2);
    Serial.print(" duty=");
    Serial.print(duty);
    Serial.print(" dutyPct=");
    Serial.print(dutyPct, 1);
    Serial.println("%");
  }
#endif

  delay(5);
}

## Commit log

2026-06-13 Add firmware and KiCad schematic for B2500 cluster PWM dimmer
    Scaffold the project per the design brief:
    - firmware/: PlatformIO project for the Seeed XIAO RP2040. Reads the
    factory rheostat via an ADC divider and drives a high-side 12V PWM
    output with gamma curve, EMA smoothing, and serial debug. Includes the
    REVERSE_DIMMER_DIRECTION option.
    - hardware/kicad/: ERC-clean schematic (0 violations) generated by
    hardware/scripts/gen_sch.py. Covers input protection (inline fuse,
    reverse-polarity diode, TVS, bulk caps), Pololu buck, XIAO, ADC sense
    divider with BAT54S clamp, and the Q1/Q2 discrete high-side switch.
    Deviations from brief for a cleaner PWM edge: R6 gate pull-up 47k->1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
    [b2500_cluster_pwm_dimmer.kicad_sch]
2026-06-13 Add KiCad PCB layout (placed + poured, signal nets for GUI routing)
    Generate b2500_cluster_pwm_dimmer.kicad_pcb via hardware/scripts/gen_pcb.py
    (pcbnew API). Per the chosen workflow, the board is delivered placed and
    ground-poured with the high-current connector nets pre-routed; the remaining
    signal nets are left as ratsnest for interactive routing in the KiCad GUI.
    - Signal-flow floorplan on a 94x62 mm 2-layer board, fitted against real
    footprint courtyards: connector left, input protection across the top,
    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
    [b2500_cluster_pwm_dimmer.kicad_pcb, b2500_cluster_pwm_dimmer.kicad_sch]
2026-06-13 Add README, fabrication notes, BOM, and fab-export tooling
    - README.md: project description, wiring/install concept, connector pinout,
    firmware build, the PCB GUI-routing finish workflow, deviations from the
    brief, and safety notes.
    - hardware/fabrication_notes.md: board spec, cluster-illumination-only
    warning, routing-status caveat, assembly notes (off-board fuse, DNP parts,
    module pin-order check), and the bench + in-vehicle test procedures.
    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
    [b2500_cluster_pwm_dimmer_bom.csv]
2026-06-13 Fully route the PCB and export fabrication gerbers
    Replace the place-and-pour-only board with a complete, DRC-clean layout
    (0 violations, 0 unconnected). gen_pcb.py now includes a self-contained
    collision-aware router:
    - 2-segment L and 3-segment swept-dogleg attempts on either copper layer,
    with a via dropped at the corner when the legs change layer; rejects any
    candidate within clearance of a foreign pad, track, or via.
    - A grid maze (Lee) fallback that guarantees a path where one exists, used
    for the nets boxed in by the XIAO pin columns and the power spines
    (e.g. 3V3, DIM_IN). Grid-discretisation safety margin keeps maze routes
    off pad/track edges.
    - High-current nets (VIN_RAW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
    [b2500_cluster_pwm_dimmer-B_Adhesive.gbr, b2500_cluster_pwm_dimmer-B_Courtyard.gbr, b2500_cluster_pwm_dimmer-B_Cu.gbr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]
2026-06-13 Fix U2 buck land: off-board 3-pin wired header (audit finding)
    A datasheet/footprint audit found the U2 land was wrong: the custom Pololu
    D36V28F5 footprint had 4 pads in an unverified order, but the real module has
    6 connections (offset PG plus two GNDs) and Pololu does not publish the edge
    pin order in text. A mis-built buck could put 12 V on the 5 V rail.
    Replace it with an orientation-proof connection: U2 is now a labeled 3-pin
    header (VIN / GND / VOUT 5V) for the module mounted off-board and wired
    label-to-label. EN (default-on) and PG are unused.
    - netlist.py: U2 -> PinHeader_1x03, pads VIN/GND/VOUT -> VIN_PROT/GND/5V_BUCK.
    - gen_sch.py: buck symbol reduced to 3 pins (VIN/GND/VOUT).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
    [b2500_cluster_pwm_dimmer-B_Adhesive.gbr, b2500_cluster_pwm_dimmer-B_Courtyard.gbr, b2500_cluster_pwm_dimmer-B_Cu.gbr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]
2026-06-16 Add green power-on LED (D6 + R11) on protected 12V input
    Lights whenever the board has power. 3mm THT green LED with a 3.3k
    series resistor (~3 mA) off VIN_PROT, placed top-right with a PWR silk
    label. Schematic gains an LED symbol; fully routed, DRC 0/0; gerbers,
    BOM, schematic PDF, and render refreshed.
    [b2500_cluster_pwm_dimmer-B_Adhesive.gbr, b2500_cluster_pwm_dimmer-B_Courtyard.gbr, b2500_cluster_pwm_dimmer-B_Cu.gbr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]
2026-06-16 Add JLCPCB CPL (pick-and-place) for assembly promo
    25 placements (DNP and test points excluded), JLCPCB column format.
    [b2500_cluster_pwm_dimmer_CPL.csv]
2026-06-16 Add JLCPCB assembly BOM (SMD parts for free-placement promo)
    [b2500_cluster_pwm_dimmer_JLCPCB_BOM.csv]
